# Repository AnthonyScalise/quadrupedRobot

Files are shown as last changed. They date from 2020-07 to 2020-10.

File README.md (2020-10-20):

# Quadruped Spider Robot

### A raspberry pi zero W based 3d printed quadruped robot written in python3.
###### Intended as a development platform for my personal learning not as a project with a defined goal or finished state.

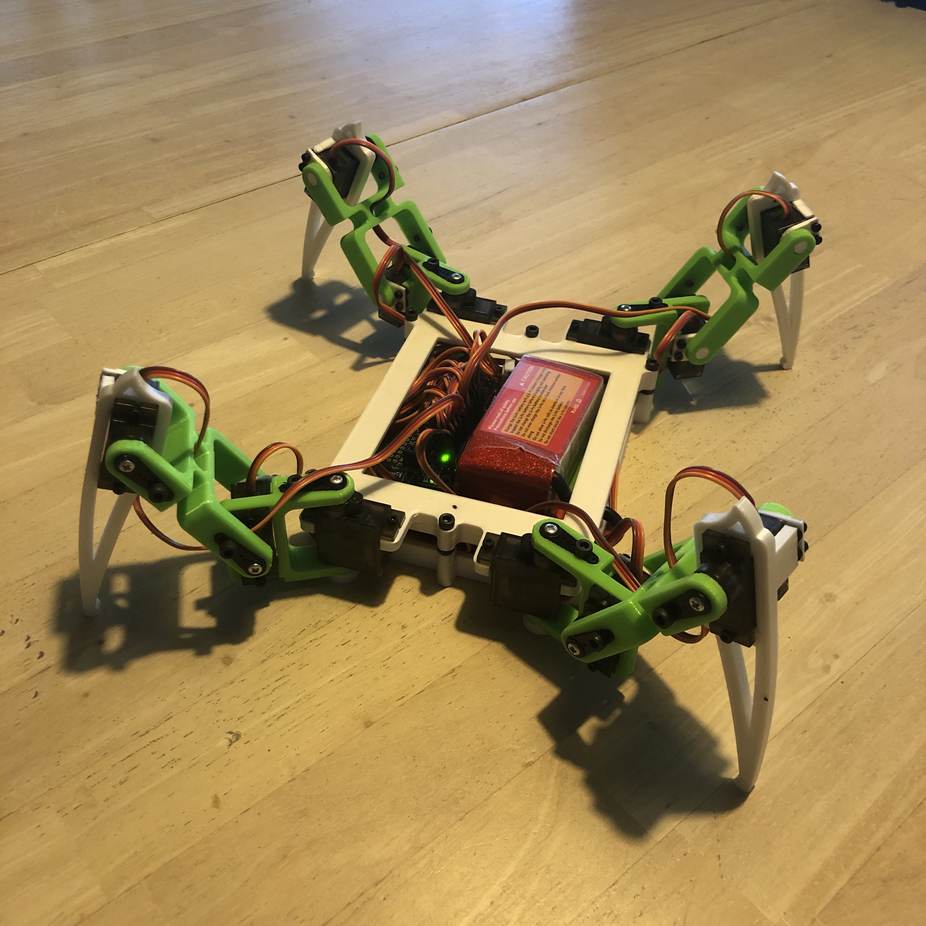
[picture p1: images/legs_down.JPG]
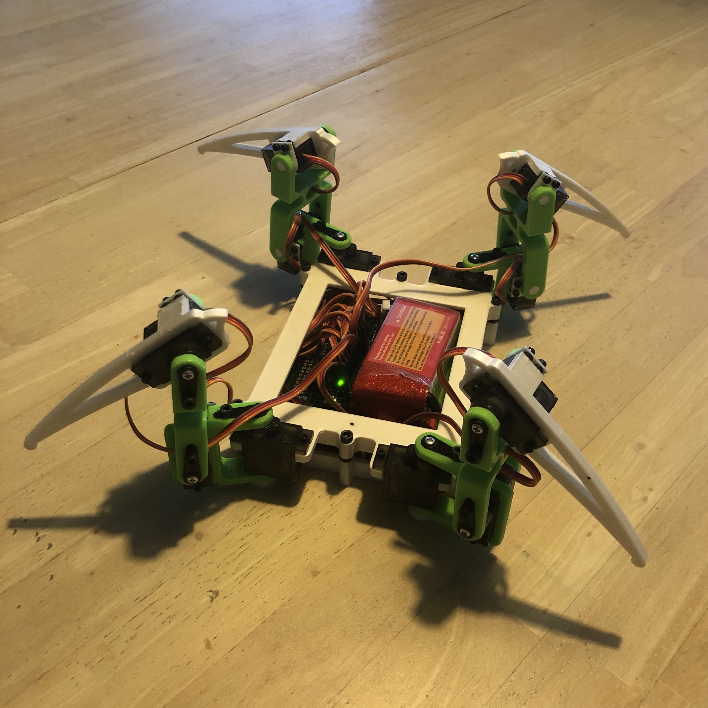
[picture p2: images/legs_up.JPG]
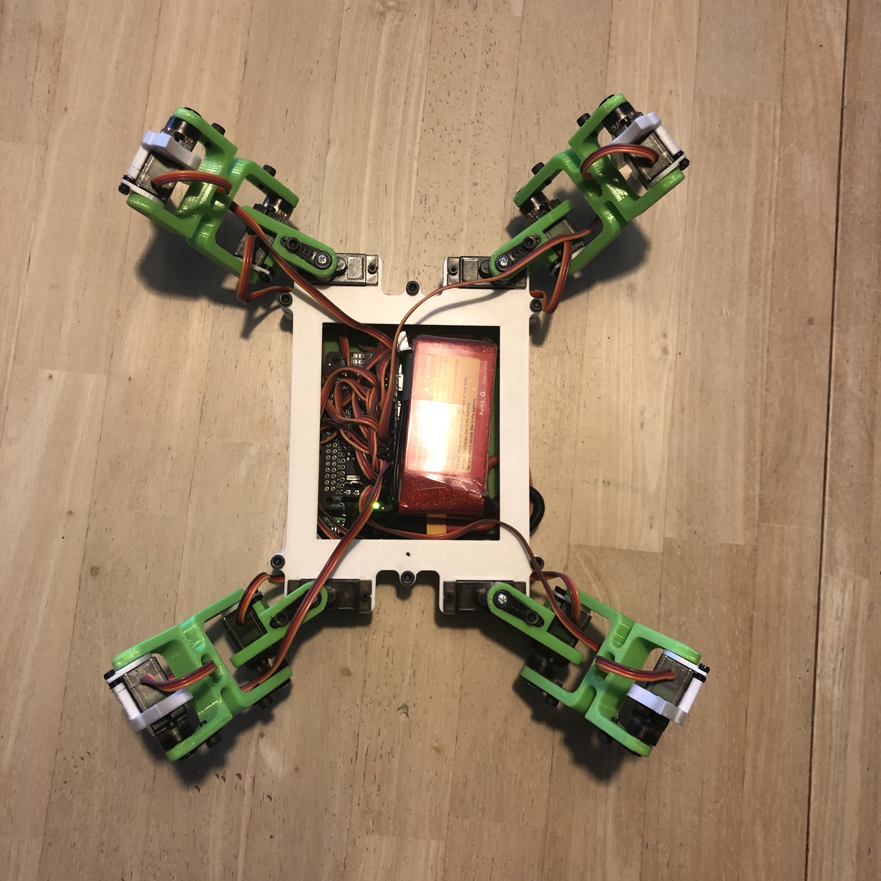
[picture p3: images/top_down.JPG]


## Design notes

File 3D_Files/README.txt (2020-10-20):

These files are for a basic skeleton only. Support for mounting electronics must be added depending
on your design. The main files are meant for use with SG90 servos. 

I found that with my design SG90 servos were not quite strong enough for what I wanted. The files in
the MG90S folder are to be used as a replacment for the corresponding main files when using MG90S
servos. I found these servos to work much much better providing more stability. 

I did however have a problem with small vibrations being transfered through the frame when the legs
are not under compression. This caused small vibrations to be amplified by the control loop in the
firmware on each of the servos resulting in the robot having intense seizure like vibrations when
picked up and lightly shaken. 

I believe that with a redesign to make the central area smaller and thus the over all structure less
heavy SG90 servos could be comfortably used and the nylon gears would provide enough vibration
dampening to avoid this oscillation issue in contrast to the metal gears on the MG90S servos.

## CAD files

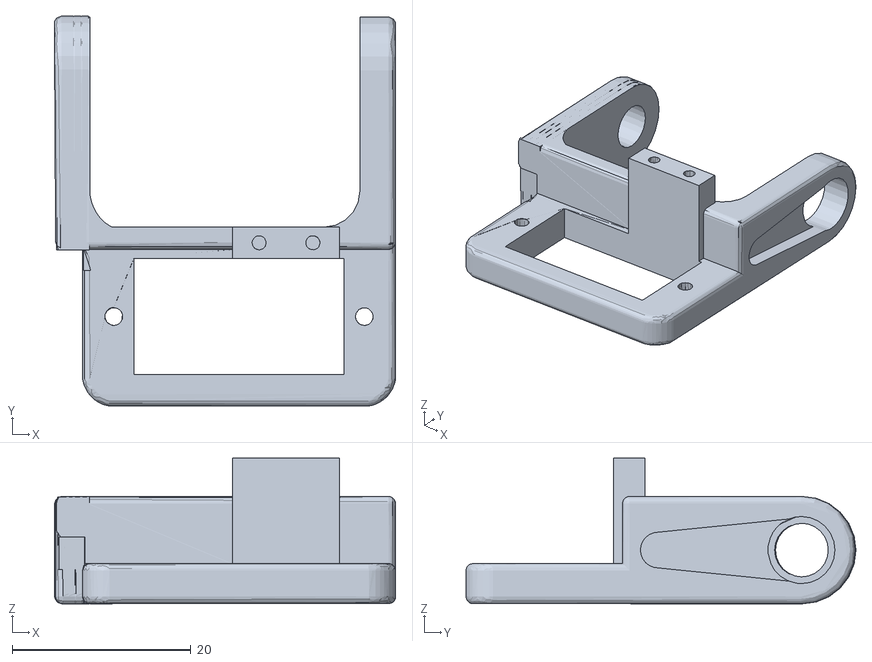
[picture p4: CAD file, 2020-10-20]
3D_Files/MG90S_compatibility_support/coxa_R.stl
38.1 x 43.6 x 16.3

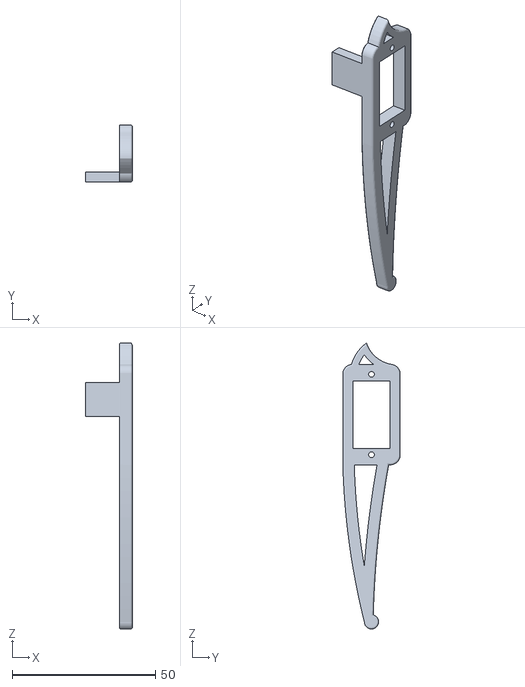
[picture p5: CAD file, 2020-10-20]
3D_Files/tibia_L.stl
16.3 x 20.0 x 99.7

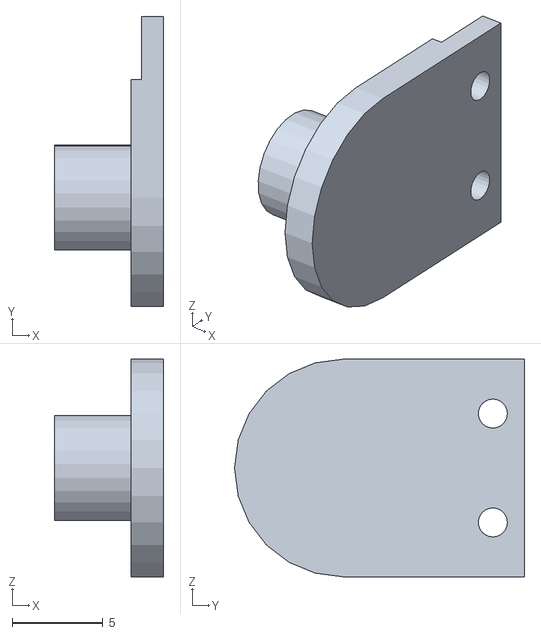
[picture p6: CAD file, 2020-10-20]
3D_Files/joint_support.stl
6.00 x 16.0 x 12.0

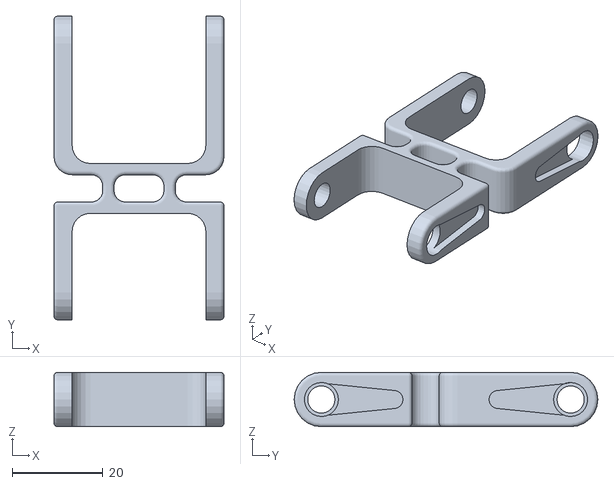
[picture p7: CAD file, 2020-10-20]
3D_Files/femur.stl
37.5 x 67.0 x 12.0

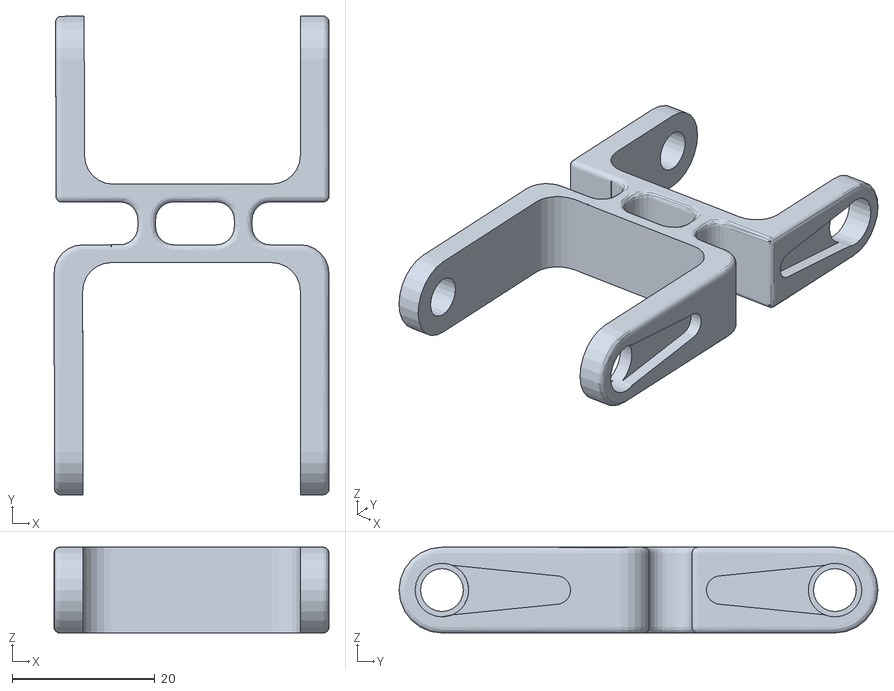
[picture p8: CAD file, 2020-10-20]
3D_Files/MG90S_compatibility_support/femur.stl
38.5 x 67.0 x 12.0

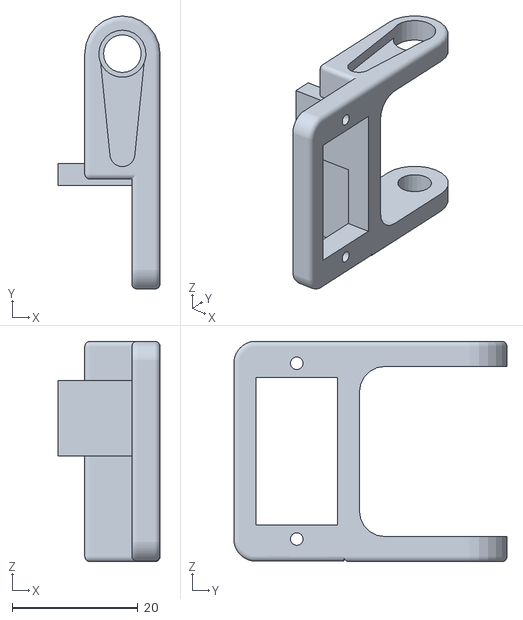
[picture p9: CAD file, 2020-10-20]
3D_Files/coxa_L.stl
16.3 x 43.5 x 35.1

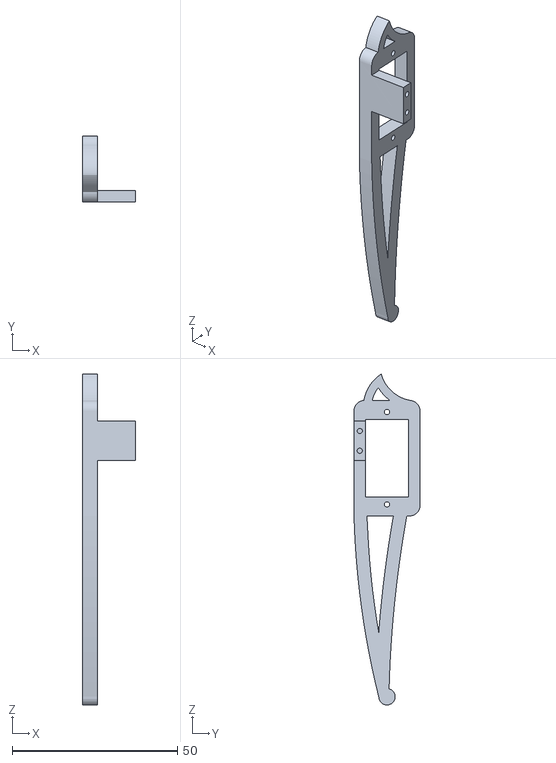
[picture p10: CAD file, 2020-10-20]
3D_Files/tibia_R.stl
16.0 x 20.0 x 100.3

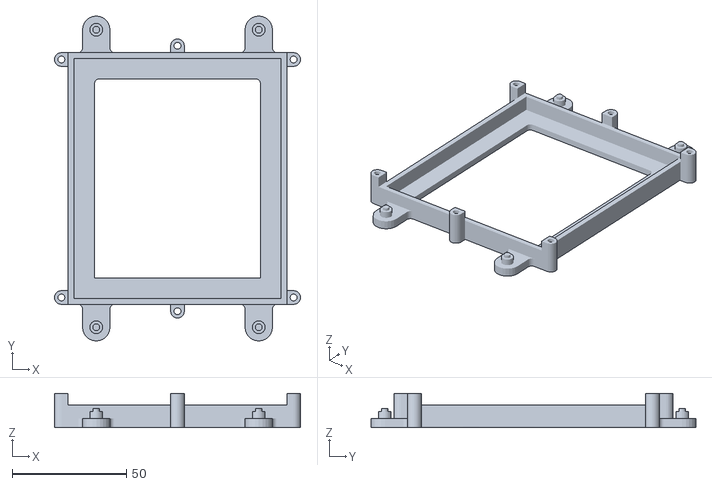
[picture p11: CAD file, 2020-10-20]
3D_Files/body_lower.STL
107.5 x 142.0 x 15.0

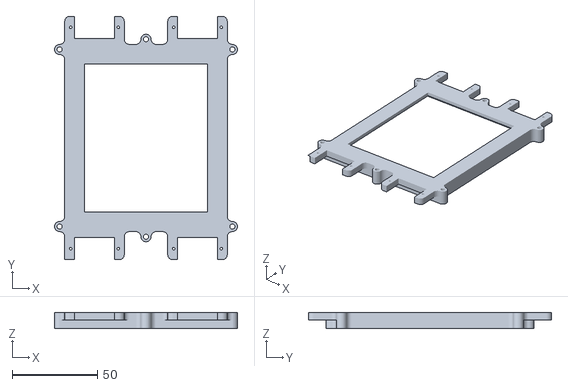
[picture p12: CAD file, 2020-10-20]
3D_Files/body_upper.STL
107.5 x 143.0 x 9.61

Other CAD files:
3D_Files/MG90S_compatibility_support/coxa_L.stl
3D_Files/coxa_R.stl

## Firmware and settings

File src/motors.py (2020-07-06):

# motors.py This file holds all data for all motors and acts as an interface between degree notation and pwm servo control

import adafruit_pca9685
import time
import json
import threading
from endpoints import *

pwm = adafruit_pca9685.PCA9685()
pwm.set_pwm_freq(60)

hips = [2, 5, 8, 11]
legs = [1, 4, 7, 10]
feet = [0, 3, 6, 9]

class Motor:
    def __init__(self, channel):
        self.channel = channel
        self.speed = 0 # a good medium speed is (0.000001)
        self.position = 370 # defualt positions of motors to protect from bottoming out
        self.degree = 0 # list of degree interpreted positions
        self.degreeConversionNum = 0 # this is the scale for converting pos into deg
        self.degreeMax = 180
        self.degreeMin = 0
        if(self.channel in hips): # sets limits for shoulders
            up = 90
            low = 0
        if(self.channel in legs): # sets limits for legs
            up = 180
            low = 0
        if(self.channel in feet): # sets limits for feet
            up = 164
            low = 53
        self.degUpLimit = up
        self.degLowLimit = low
        self.mode = 0
        self.mid = 0
        self.max = 0
        self.min = 0
        self.direction = 0
        self.motorTarget = 0
        self.settingEvent = threading.Event()


    def motorEstop(self):
        pwm.set_pwm(self.channel, 4096, 0)

    def getDegPos(self):
        return self.degree


    def posToDeg(self, pos):
        deg = 0
        if(self.direction==1):
            deg = (pos-self.min)
        if(self.direction==(-1)):
            deg = (pos-self.max)
        deg = int(deg*self.degreeConversionNum)
        return deg


    def mapValue(self, value):
        degSpan = self.degreeMax - self.degreeMin
        posSpan = self.max - self.min
        valueScaled = float(value - self.degreeMin) / float(degSpan)
        return int(self.min + (valueScaled * posSpan))


    def setSpeed(self, speed):
        self.speed = speed


    def setDeg(self, degTarget):
        if degTarget > self.degUpLimit:
            degTarget = self.degUpLimit
        if degTarget < self.degLowLimit:
            degTarget = self.degLowLimit
        self.degree = degTarget
        target = self.mapValue(degTarget)
        self.setPos(target)


    def setPos(self, target):
        if(self.speed == 0):
            self.motorTarget = target
        else:
            threading.Thread(target=self.setPosWithSpeed, args=(target,)).start()


    def setPosWithSpeed(self, target):
        with threading.lock():
            direction = 1
            if(self.position >= target):
                direction = -1
            targetLocalCopy = target
        for pos in range(self.position, (target+direction), direction):
            if target == targetLocalCopy:
                self.motorTarget = pos
                time.sleep(self.speed)
            else:
                break


    def sendPosToMotor(self, pos):
        while not self.settingEvent.is_set():
            self.settingEvent.set()
            pwm.set_pwm(self.channel, 0, pos)
            self.position = pos
            self.settingEvent.clear()


motorList = [Motor(i) for i in range(12)] # one dimentional list of all motor objects
positions = [motorList[i].position for i in range(12)] # list of all positions in motorList order
legList = [[motorList[i] for i in range(3)], [motorList[i] for i in range(3, 6)], [motorList[i] for i in range(6, 9)], [motorList[i] for i in range(9, 12)]]


def updateMotors():
    while True:
        for motor in motorList:
            threading.Thread(target=motor.sendPosToMotor, args=(motor.motorTarget,)).start()


def estop():
    for motor in motorList:
        motor.motorEstop()


def setLegPos(legNum, speed=0, hipAng=0, legAng=0, footAng=0):
    directions = [1, 1, 1]
    targets = [footAng, legAng, hipAng]
    joints = [legList[legNum][i] for i in range(3)]
    for i in range(3):
        if joints[i].degree > targets[i]:
            directions[i] = -1
            if targets[i] < joints[i].degLowLimit:
                targets[i] = joints[i].degLowLimit
        else:
            if targets[i] > joints[i].degUpLimit:
                targets[i] = joints[i].degUpLimit
    if speed == 0:
        for i in range(2, -1, -1):
            joints[i].setDeg(targets[i])
            return
    else:
        while((joints[0].degree != targets[0]) or (joints[1].degree != targets[1]) or (joints[2].degree != targets[2])):
            for i in range(2, -1, -1):
                if (joints[i].degree != targets[i]):
                    joints[i].setDeg(joints[i].degree + directions[i])
            time.sleep(speed)


def syncSaves():
    print('Initializing bot motors...\n')
    with open('calibrationProfile.txt') as limits_file:
        limitProfile = json.load(limits_file)
    for motor in motorList:
        i = motor.channel
        motor.min = limitProfile['min'][i]
        motor.max = limitProfile['max'][i]
        motor.mid = limitProfile['mid'][i]
        if(motor.min < motor.max):
            motor.mode = (motor.max-motor.min)
            motor.direction = 1
        if(motor.max < motor.min):
            motor.mode = (motor.min-motor.max)
            motor.direction = -1
    for i in range(12):
        motorList[i].degreeConversionNum = (180/motorList[i].mode)


def initialSit():
    setHips(45)
    setLegs(150)
    setFeet(53)
    time.sleep(1)
    estop()

def initialStand():
    setHips(45)
    setLegs(100)
    setFeet(85)


def setHips(deg):
    for i in hips:
        motorList[i].setDeg(deg)

def setLegs(deg):
    for i in legs:
        motorList[i].setDeg(deg)

def setFeet(deg):
    for i in feet:
        motorList[i].setDeg(deg)


def getMotorsTable(): # Returns a multidimentional table of the motors respective to their legs
    motors = []
    cols=0
    while(cols<12):
        motors.append([])
        for rows in range(3):
            motors[int(cols/3)].append(motorList[cols+rows])
        cols+=3
    return(motors)


def moveUpAndDownTest():
    print('Moving up and down test\n')
    while True:
        height = int(input('    Enter a height in mm: '))
        for point in endpointList:
            point.setPointUpDown(30, 30, height, legDegree=90)
            setLegPos(point.leg, hipAng=point.getHipDeg(), legAng=point.getLegDeg(), footAng=point.getFootDeg())
        print('\n')
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

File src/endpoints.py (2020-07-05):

# This class handles all inverse kinematics endpoint functions for motors.py to use

import math

footLen = 67.328 #mm
legLen = 51.446 #mm
hipLen = 27.40 #mm

hipHeight = 30 #mm

minX = -48.594 #mm
maxX = 161.283 #mm
minY = 0 #mm
maxY = 161.283 #mm
minZ = -132.27209 #mm
maxZ = 133.883 #mm

legTrim = -48
footTrim = 41

class Endpoint:
    def __init__(self, leg):
        self.leg = leg
        self.x = 0
        self.y = 0
        self.z = 0
        self.legFootPlaneX = 0
        self.legFootPlaneY = 0
        self.legFootPlaneHypo = 0
        self.footDeg = 0
        self.legDeg = 0
        self.hipDeg = 0

    def setPointUpDown(self, x, y, z, legDegree):
        self.x = x
        self.y = y
        self.z = z
        self.legDeg = legDegree
        self.hipDeg = math.degrees(math.atan(self.y / self.x))
        self.legFootPlaneX = ((self.x * math.cos(math.radians(self.hipDeg)))-hip)
        self.legFootPlaneY = self.z + hipHeight
        self.legFootPlaneHypo = math.sqrt((math.pow(self.legFootPlaneX, 2)+math.pow(self.legFootPlaneY, 2)))
        self.footDeg = math.degrees(math.asin((math.sin(math.radians(legDegree))/foot)*self.legFootPlaneHypo))

    #def setPositionForwardBack(self, x, y, z, ):

#    def solveKinematics(self, x, y, z):
#        self.x = x
#        self.y = y
#        self.z = z
#        self.hipDeg = math.degrees(math.atan2(y, x))
#        legDegreeA = (math.atan2(z, legLen))
#        legDiag = math.sqrt(math.pow(legLen, 2) + math.pow(x, 2))
#        legDegreeB = math.acos((math.pow(legLen, 2) + math.pow(legDiag, 2) - math.pow(footLen, 2))/(2 * legLen * legDiag))
#        self.legDeg = (math.degrees(legDegreeA+legDegreeB)) + legTrim
#        self.footDeg = (math.degrees(math.acos((math.pow(legLen, 2) + math.pow(footLen, 2) - math.pow(legDiag, 2))/(2 * legLen * footLen)))) + footTrim

    def solveKinematics(self, x, y, z):
        self.x = x
        self.y = y
        self.z = z
        hipFootDiag = math.sqrt(math.pow(x, 2) + math.pow(y, 2))
        self.hipDeg = math.degrees(math.atan2(y, x))
        legFootX = (hipFootDiag - hipLen)
        legFootHypo = math.sqrt(math.pow(legFootX, 2) + math.pow(z, 2))
        legDegPartA = math.degrees(math.atan2(legFootX, z))
        legDegPartB = math.degrees(math.acos((math.pow(legFootHypo, 2) + math.pow(legLen, 2) - math.pow(footLen, 2)) / (2 * legFootHypo * legLen)))
        self.legDeg = (legDegPartA + legDegPartB)
        self.footDeg = math.degrees(math.acos((math.pow(legLen, 2) + math.pow(footLen, 2) - math.pow(legFootHypo, 2)) / (2 * legLen * footLen)))


    def getFootDeg(self):
        return self.footDeg

    def getLegDeg(self):
        return self.legDeg

    def getHipDeg(self):
        return self.hipDeg

endpointList = [Endpoint(i) for i in range(4)]

def getEndpointList():
    return endpointList

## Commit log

2020-06-15 first comm
    [calibrationConfig.txt]
2020-06-19 Adding code for 180 degree servo calibration
2020-06-19 Fixed bugs in calibrate for 180 degree servos
    [calibrate.py]
2020-06-19 Added calibrationProfile save file
2020-06-23 Fixed bugs in calibrate.py and started calibrationProfile.txt setup
    [calibrationConfig.txt]
2020-06-24 Added new inverse kinematics class for positions and added funtion to control leg groups in motor.py
2020-06-24 Finished up down inverse kinematics test function
2020-06-25 Calibrated hips and legs and fixed bugs in endpoints.py
    [calibrate.py, endpoints.py, motors.py]
2020-06-26 Removed legacy files, added testingUtils.py to aid in cli development
    [calibrationConfig.txt]
2020-06-26 Fixed testingUtils.py tabs spacing
    [endpoints.py, testingUtils.py]
2020-06-26 Fixed bug in testingUtils.py
    [testingUtils.py]
2020-06-27 Fixed setLegPos bugs in motors.py, expanded on estop
    [motors.py, testingUtils.py]
2020-06-27 Finished first full calibration, fixed some bugs in endpoints.py
    [calibrate.py, endpoints.py, motors.py]
2020-06-27 Added new inverse kinematics algorithim and testing funtionality
2020-06-27 Tested and tuned inverse kinematics. More testing necessary
2020-07-01 Added working kinematics model to endpoints.py corected kinematicsTest in motors.py
2020-07-05 Fixed bug: solveKinematics now has proper calculation, has been tested and works. May need tunning distance offsets
    [endpoints.py]
2020-07-06 Added support for threading scheduler
2020-07-06 Fixed bug in scheduler, needs physical testing
    [motors.py]
2020-10-20 Added 3D files
    [body_lower.STL, body_upper.STL, coxa_L.stl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]
